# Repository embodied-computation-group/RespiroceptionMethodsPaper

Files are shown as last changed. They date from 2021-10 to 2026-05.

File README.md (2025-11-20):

# The Respiratory Resistance Sensitivity Task: An Automated Method for Quantifying Respiratory Interoception and Metacognition

This repository contains data, code and supporting documents for the manuscript:

https://www.biorxiv.org/content/10.1101/2021.10.14.464418v1

Please cite as:

>Nikolova, N., Harrison, O. K., Toohey, S., Braendholt, M., Legrand, N., Correa, C. C., Vejlo, M., Fardo, F., & Allen, M. (2021). The Respiratory Resistance Sensitivity Task: An Automated Method for Quantifying Respiratory Interoception and Metacognition. BioRxiv, 2021.10.14.464418. https://doi.org/10.1101/2021.10.14.464418

# Abstract
>The ability to sense, monitor, and control respiration - e.g., respiratory interoception (henceforth, respiroception) is a core homeostatic ability. Beyond the regulation of gas exchange, enhanced awareness of respiratory sensations is directly related to psychiatric symptoms such as panic and anxiety. Indeed, chronic breathlessness (dyspnea) is associated with a fourfold increase in the risk of developing depression and anxiety, and the regulation of the breath is a key aspect of many mindfulness-based approaches to the treatment of mental illness. Physiologically speaking, the ability to accurately monitor respiratory sensations is important for optimizing cardiorespiratory function during athletic exertion, and can be a key indicator of illness. Given the important role of respiroception in mental and physical health, it is unsurprising that there is increased interest in the quantification of respiratory psychophysiology across different perceptual and metacognitive levels of the psychological hierarchy. Compared to other more popular modalities of interoception, such as in the cardiac domain, there are relatively few methods available for measuring aspects of respiroception. Existing inspiratory loading tasks are difficult to administer and frequently require expensive medical equipment, or offer poor granularity in their quantification of respiratory-related perceptual ability. To facilitate the study of respiroception, we here present a new, fully automated and computer-controlled apparatus and psychophysiological method, which can flexibly and easily measure respiratory-related interoceptive sensitivity, bias and metacognition, in as little as 30 minutes of testing, using easy to make 3D printable parts. 

# Data
All anonymized trial and group-level data associated with this manuscript can be found here:

https://github.com/embodied-computation-group/RespiroceptionMethodsPaper/tree/main/data

# Code

This repository contains all needed code to run the RRST itself, as well as associated data preprocessing and analysis scripts.

# Figures

## Figure 1 - The Respiratory Resistance Sensitivity Task - Apparatus and Design
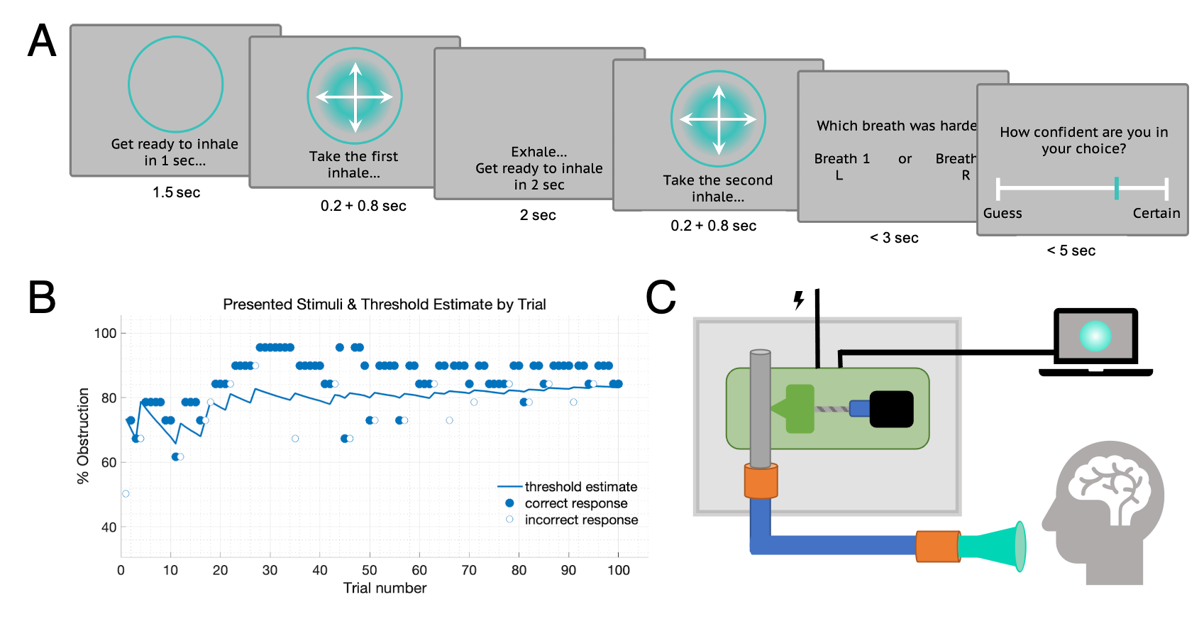
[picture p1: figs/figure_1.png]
f1


>Figure 1: The Respiratory Resistance Discrimination Task. A) Trial schematic depicting the 2-interval forced choice (2IFC) design of the task. On each trial participants view a circular cue instructing them to prepare to inhale. The circle then blinks and begins expanding, with the participant instructed to sharply inhale with the expansion of the circle. The participant then exhales, and a second similarly guided breath is conducted. This procedure of pacing the participant’s breathing via visual cues is a novel feature of the RRST, and is intended to reduce intra- and inter-subject variance in respiratory effort. Following the two breaths, the participant indicates by keyboard press whether the first or second breath was more difficult. B) Sample single subject data, illustrating the psychophysical procedure. On each trial, one of two breaths is randomly signal minus (s-), such that the compression wedge is at resting baseline (0% obstruction) with no added resistance, and the other signal plus (s+) with some level of compression determined by the staircase procedure. The procedure rapidly hones in on a threshold estimate using a Bayesian procedure (psi); in this example the participant threshold of approximately 80% obstruction is found within just 20 trials. C) Schematic illustrating the design of the automated resistive load apparatus (see Supplementary Material 1 - Detailed schematic for details). 

## Figure 2 - Respiratory Psychophysical Functions
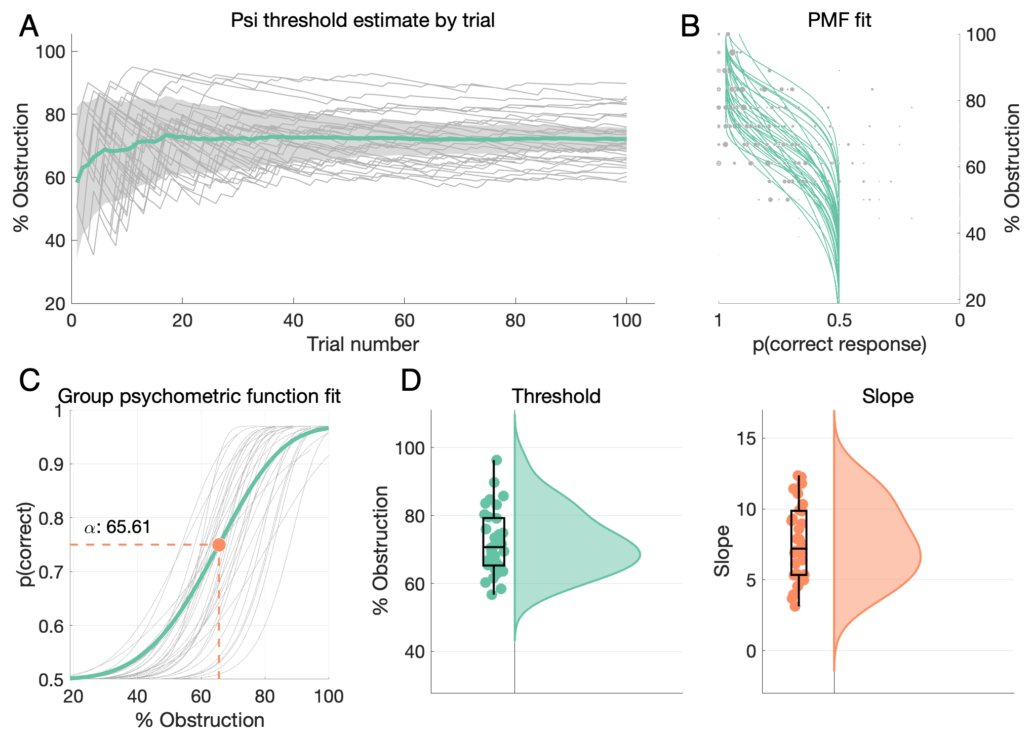
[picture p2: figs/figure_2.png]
f2


>Figure 2: Psychometric task results. A) Plot depicting trial-by-trial Psi threshold estimates for all participants. Light gray lines depict individual stimulus traces indicating the % of tube obstruction on the stimulus breath for each trial, the thick green line represents grand mean stimulus on each trial +- SEM. In general, threshold estimates stabilize around trials 20-40 for all participants. B) PMF fits for all subjects. The green lines depict individuals’ PMF fits, and grey points show stimulus levels presented, where the dot size indicates the number of times presented. C) Grand mean psychometric fit (green) overlaid on individual PMF fits (grey), demonstrating that average respiratory thresholds are around 66% airway obstruction, with substantive inter-individual variance around this value. D) Raincloud plots (Allen, Poggiali, et al., 2019) depicting individual threshold (green) and slope (orange) estimates for all subjects. 

## Figure 3 - Task Accuracy, Reaction Time, and Accuracy
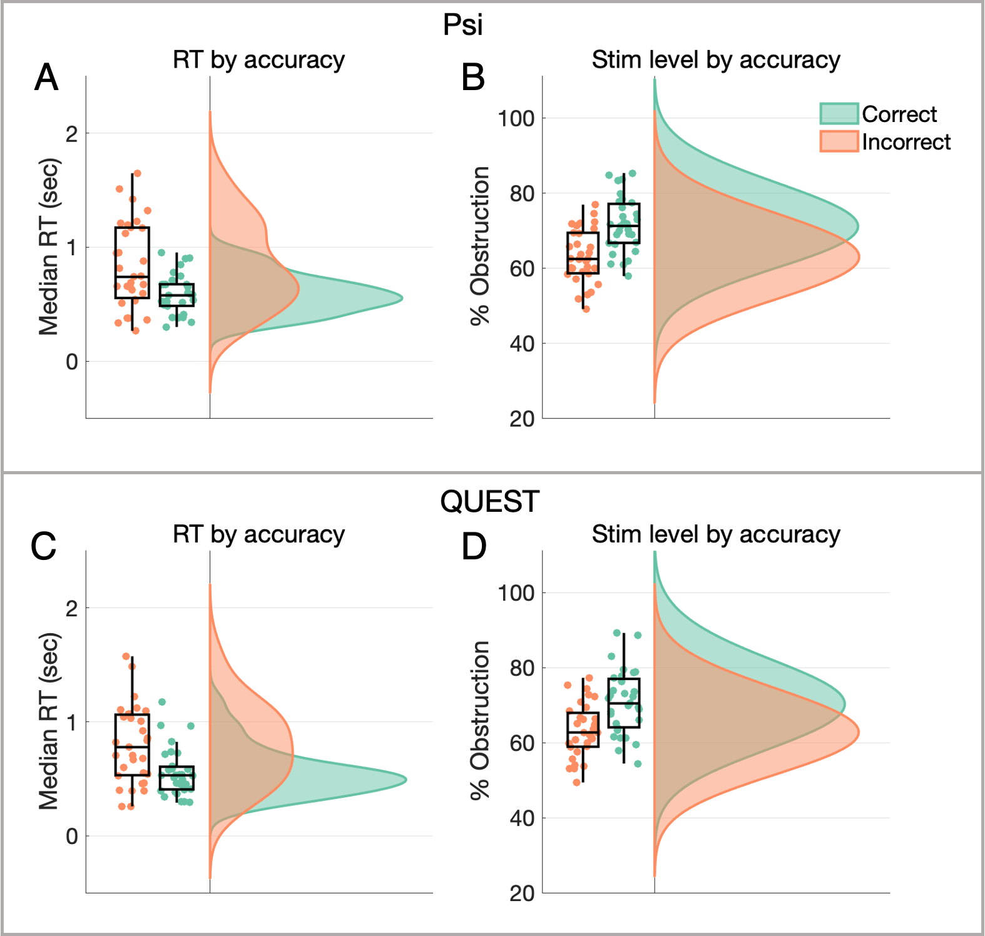
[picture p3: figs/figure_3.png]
f3


>Figure 3: Type 1 performance on Psi & QUEST methods. Raincloud plots of reaction times (RT, left panel) and stimulus level (right panel) by accuracy (correct vs. incorrect) for the Psi (upper panel) and QUEST (lower panel) staircase methods. A) & C) Median RTs presented for each subject, for correct (green) and incorrect (orange) trials showing that RTs on correct trials are lower than on incorrect trials. B) & D) Average stimulus levels presented for each subject, for correct and incorrect trials, showing that stimuli were higher (i.e., easier) on correct trials.  These results indicate good overall convergence of estimated psychometric thresholds. 

## Figure 4 - Staircase Convergence and Reliability
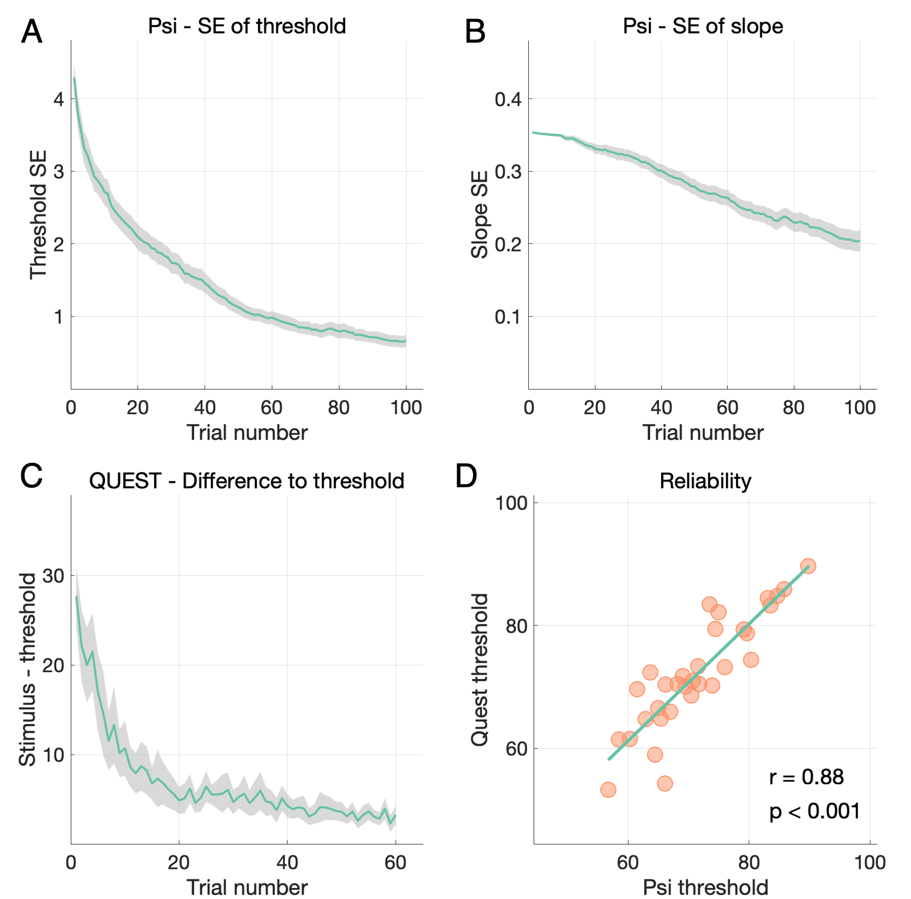
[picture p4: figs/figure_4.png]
f4


>Figure 4: Staircase convergence and Task Reliability.  A) Standard errors of the threshold estimate by trial number obtained with Psi indicate that reliable threshold estimates are derived within 20-50 trials. B) Standard errors of the slope estimate by trial number show that slope uncertainty drops linearly as a function of trials, indicating that slope estimates may benefit from higher trial numbers and/or hierarchical modelling. C) The difference to the final threshold estimates by trial number obtained with QUEST indicates that threshold estimates also converge within 20-50 trials. D) Correlation plot across the two (counter-balanced) QUEST and Psi threshold estimates indicates a high within-subject reliability of respiroceptive thresholds, regardless of estimation technique.

## Figure 5 - Respiratory Metacognition
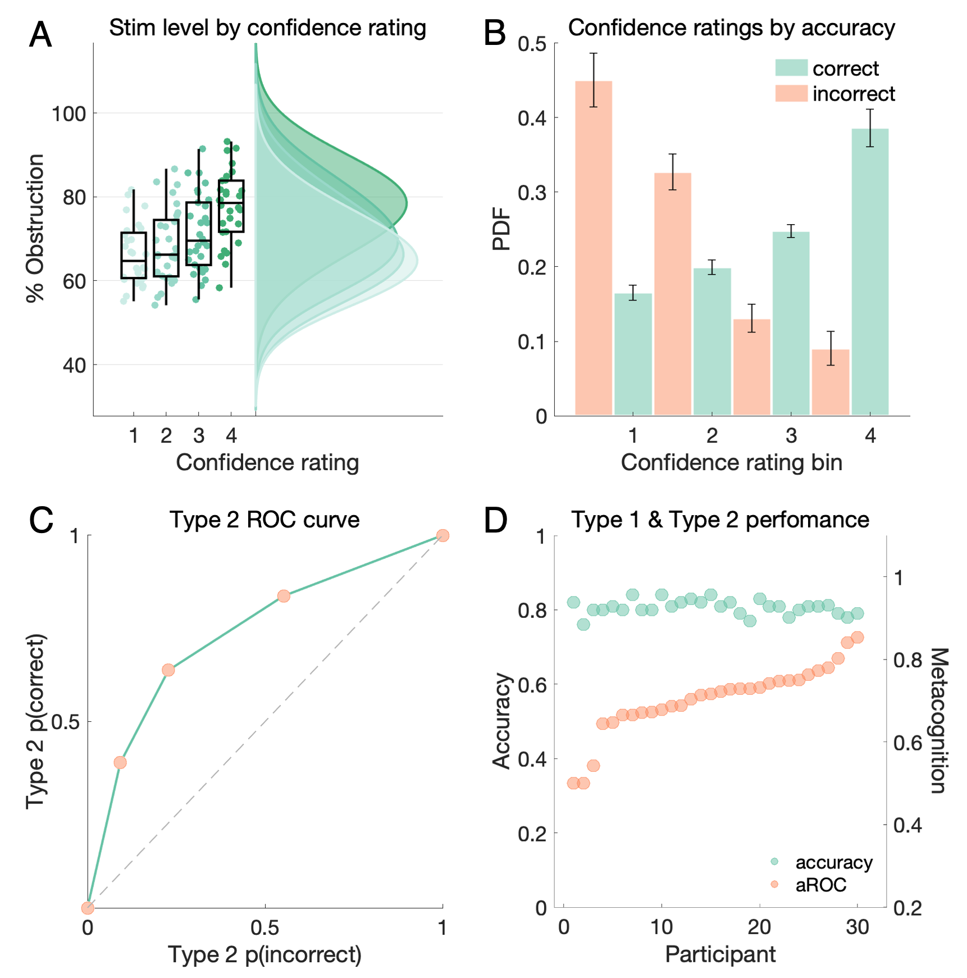
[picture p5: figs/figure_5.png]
f5


>Figure 5: Type 2 performance.  A)  Raincloud plot showing stimulus level by confidence rating, showing higher confidence ratings for stimuli with greater resistance. B)  Histogram of binned confidence ratings for correct (green) and incorrect (orange) trials. Generally, participants showed high metacognitive sensitivity, as seen in the dissociation between the correct and incorrect trial ratings. C) Type 2 ROC curve, averaged over participants, showing good respiroceptive type 2 performance. D) Type 1 (accuracy, green) and type 2 (aROC, orange) performance, sorted by each participant’s aROC. Participants show substantial variations in metacognition while type 1 accuracy is held relatively constant by the Psi staircase procedure. 

## Figure 6 - Stimulus Averiseness and other Symptoms
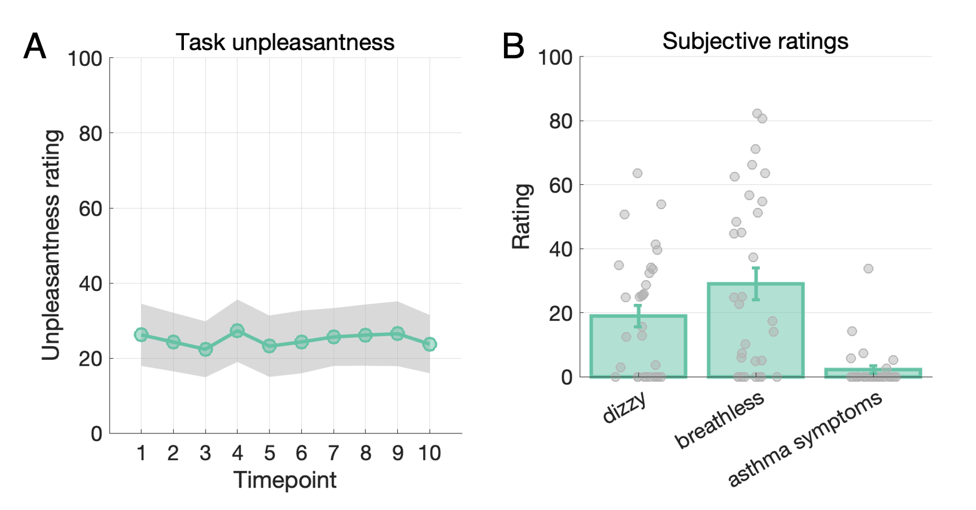
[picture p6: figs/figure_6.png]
f6


>Figure 6: Task tolerance & subjective ratings. A) Plot depicting aversiveness ratings across all 10 blocks (timepoints) of testing. Mean aversiveness ratings after each block are shown in green, and the shaded gray area represents standard error of the mean (SEM). Each block comprised 20 trials, for a total testing time of approximately 45 minutes. Participants on average reported roughly 20% stimulus aversiveness (out of 100 total), which remains stable throughout the testing period. This indicates that the stimuli were mildly unpleasant and that extended testing time did not increase task adversity within these limits. B) Plot depicting mean dizziness, breathlessness and asthma symptoms across participants. Bar height represents mean ratings, error bars denote SEM, and gray circles show individual participants’ ratings. In general, participants showed low levels of these adverse effects following 1 full hour of testing, indicating good tolerability of the task. 

# Device specifications and parts

## May 2022
We have made an update to the RRST appratus harware and software. 
An updated parts list for the device is available at: https://docs.google.com/spreadsheets/d/1Xm-xjyxZgqfn2RlGidUxHrNGNTMF7fd8MpfaUctbE9U/edit?usp=sharing
New versions of the 3d printing files, PCB design, and code for running the task are available in ./task/RRS_3-0
Instructions for setting up and running the RRST can be found here: https://docs.google.com/document/d/1KxjABdMcecnZfaXCnsQhJQzVfaNqk7DXVoDFSJKMT78/edit?usp=sharing
(Note that these were created for data collection during the COVID pandemic, and therefore include more sanitisation procedures than would usually be necessary.)

## November 2025 Update
Fixed an issue where the expanding ring stimulus was not scaling correctly on high-resolution displays. The stimulus is now generated programmatically (`showExpandingRingGenerated.m`) instead of using a pre-rendered movie file, ensuring consistent sizing and timing across different screen resolutions. This change has been applied to both the main task and the tutorial. The original movie-based method (`showExpandingRing.m`) is preserved in the codebase but commented out in the calling scripts.

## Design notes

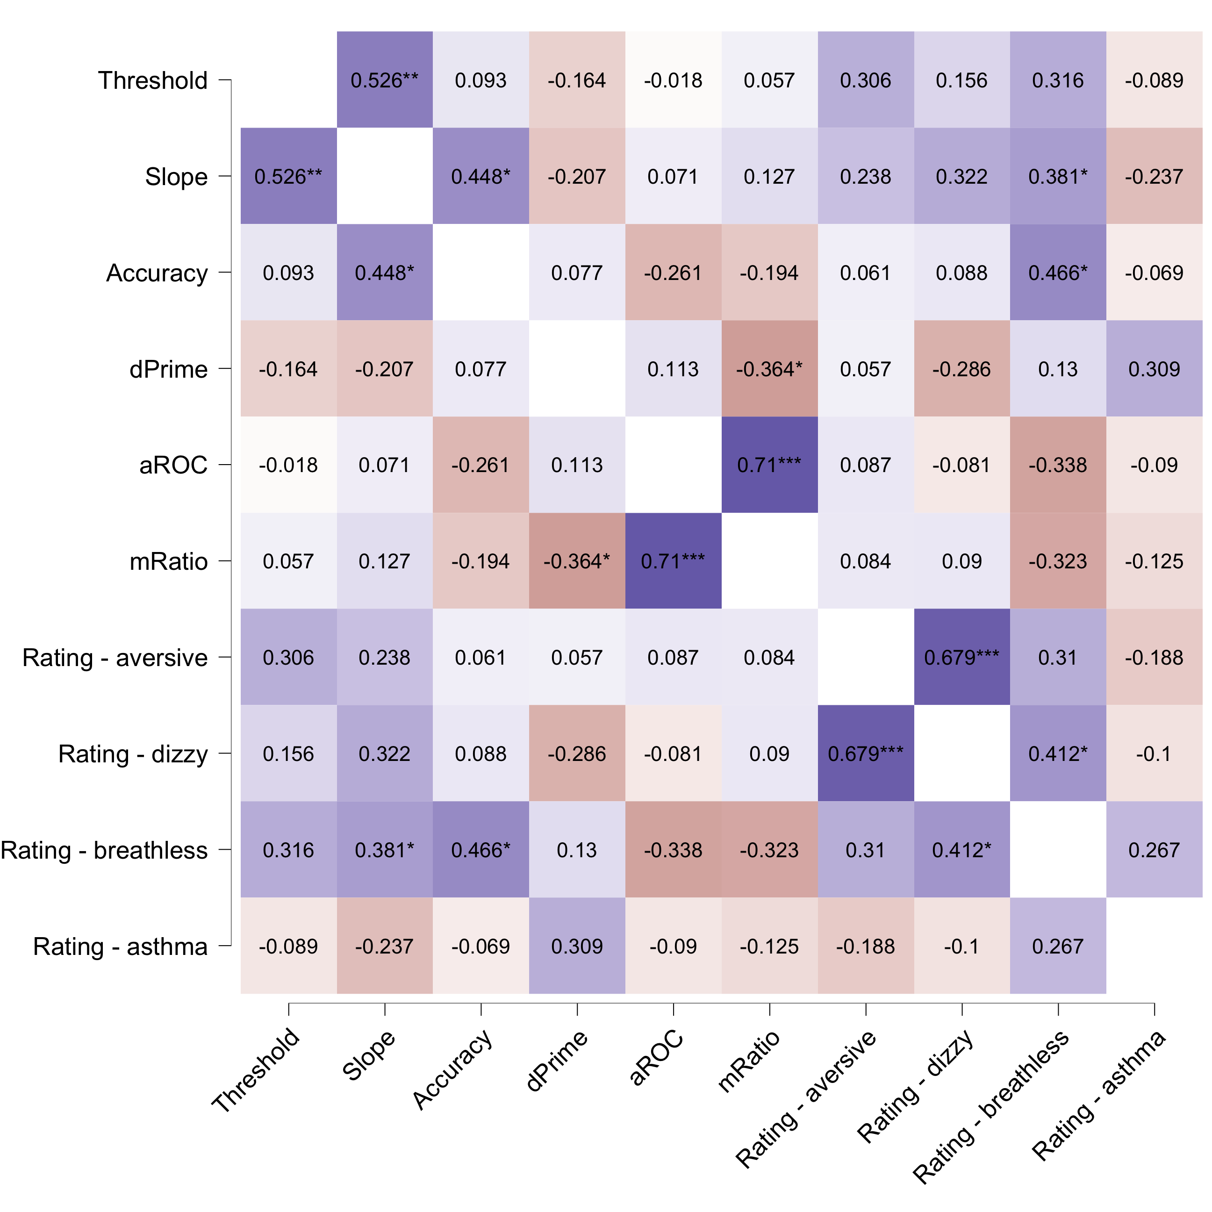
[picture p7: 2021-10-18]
figs/RRST_MP_suppfig_2.png

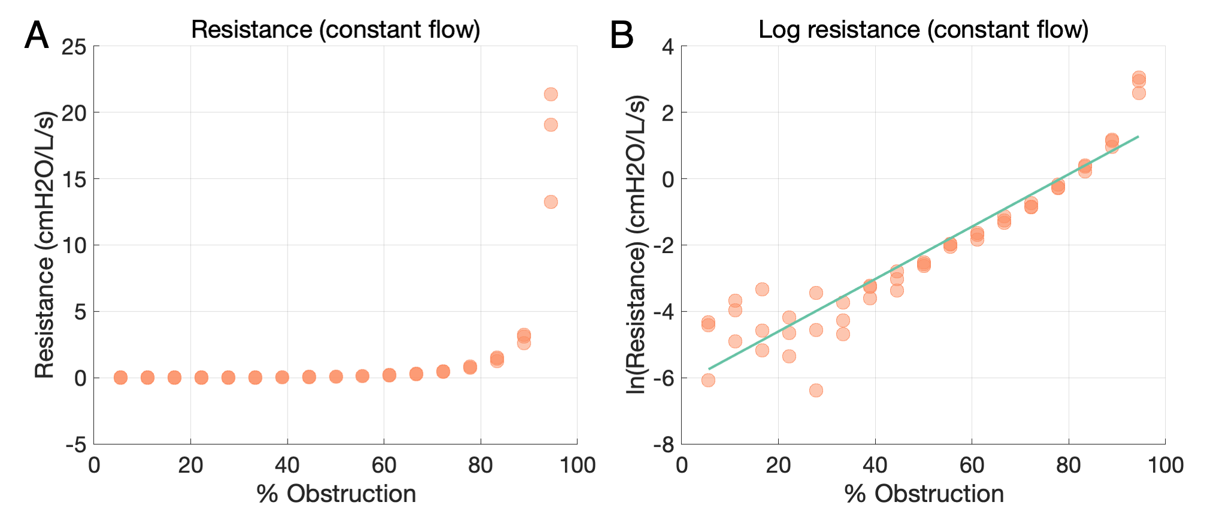
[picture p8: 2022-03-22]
figs/figure_7.png

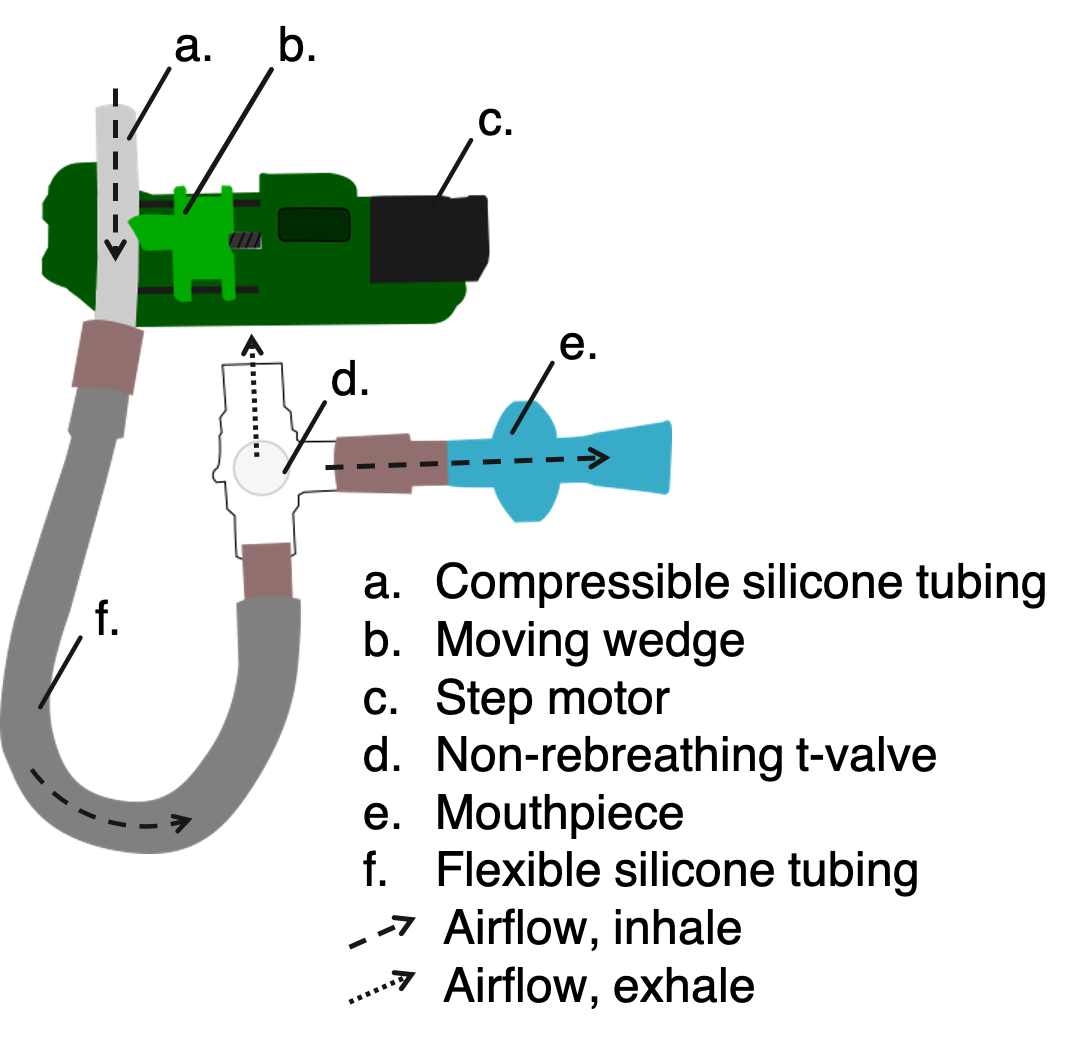
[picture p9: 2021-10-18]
figs/RRST_MP_suppfig_1.png

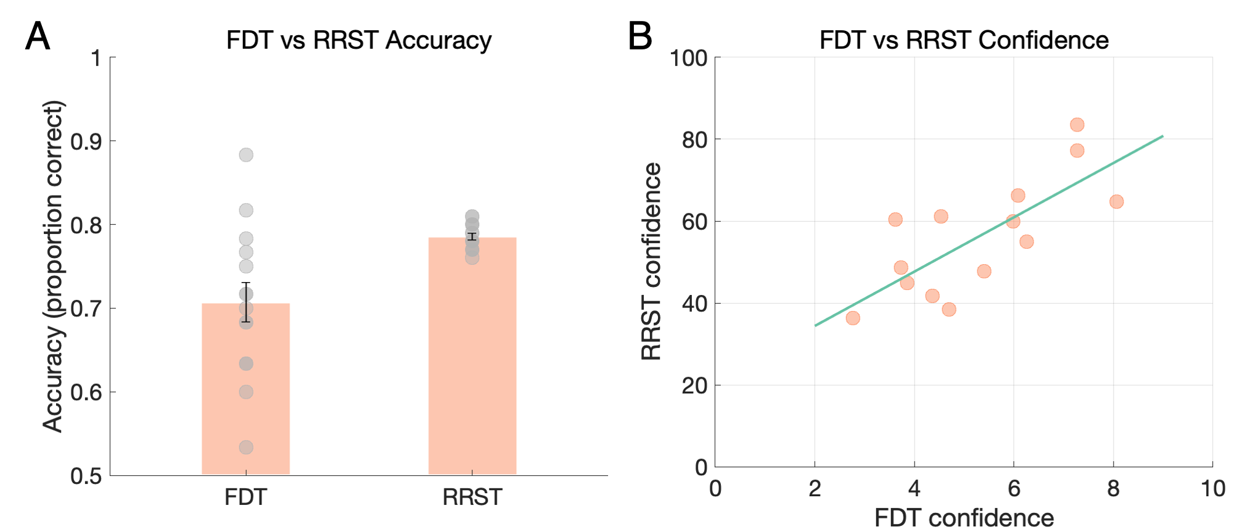
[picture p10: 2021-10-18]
figs/figure_9.png

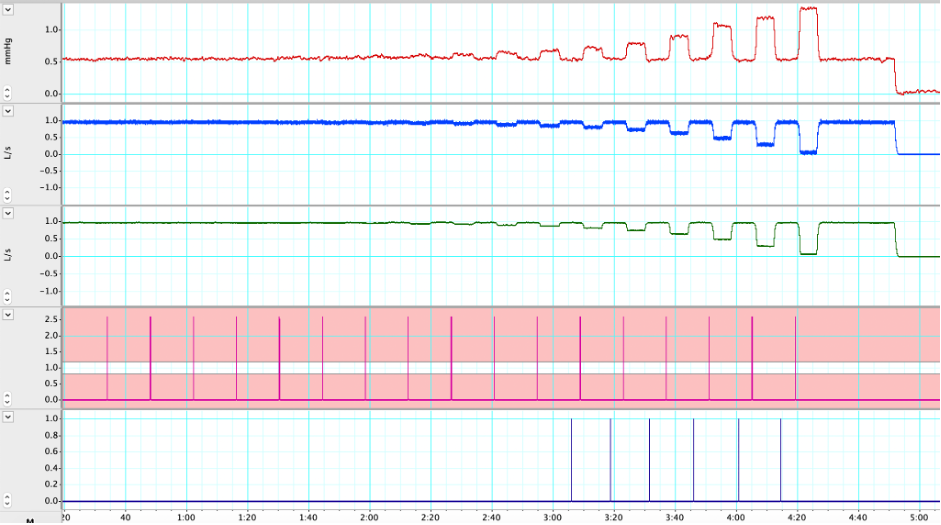
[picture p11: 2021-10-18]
figs/RRST_MP_suppfig_4.png

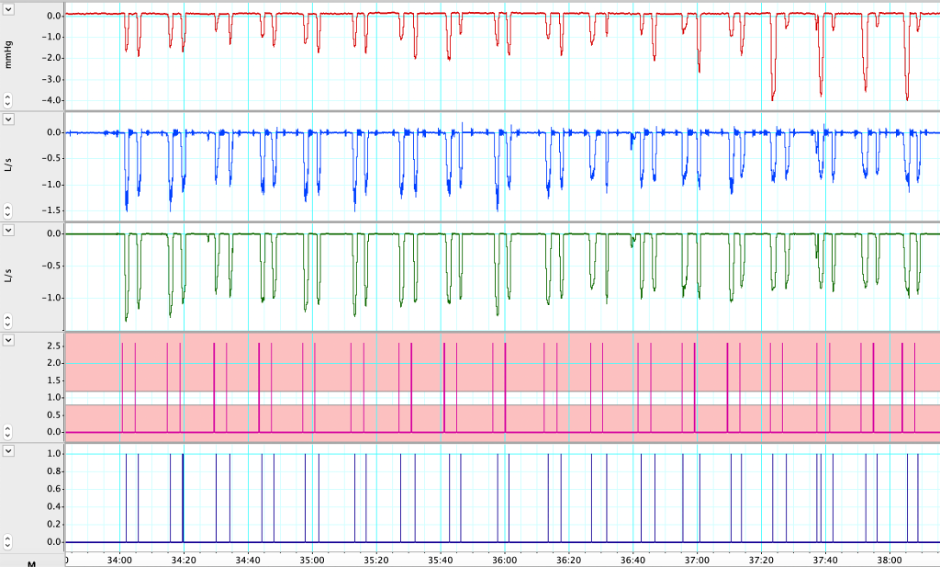
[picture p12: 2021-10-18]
figs/RRST_MP_suppfig_5.png

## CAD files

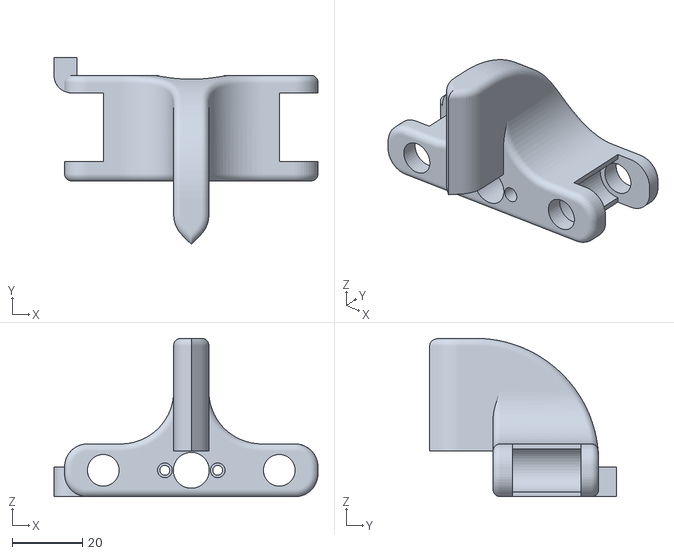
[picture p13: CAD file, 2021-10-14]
task/apparatus/version_2-2/3dPrintStlFiles/Vice_clamp.stl
75.0 x 53.0 x 45.0

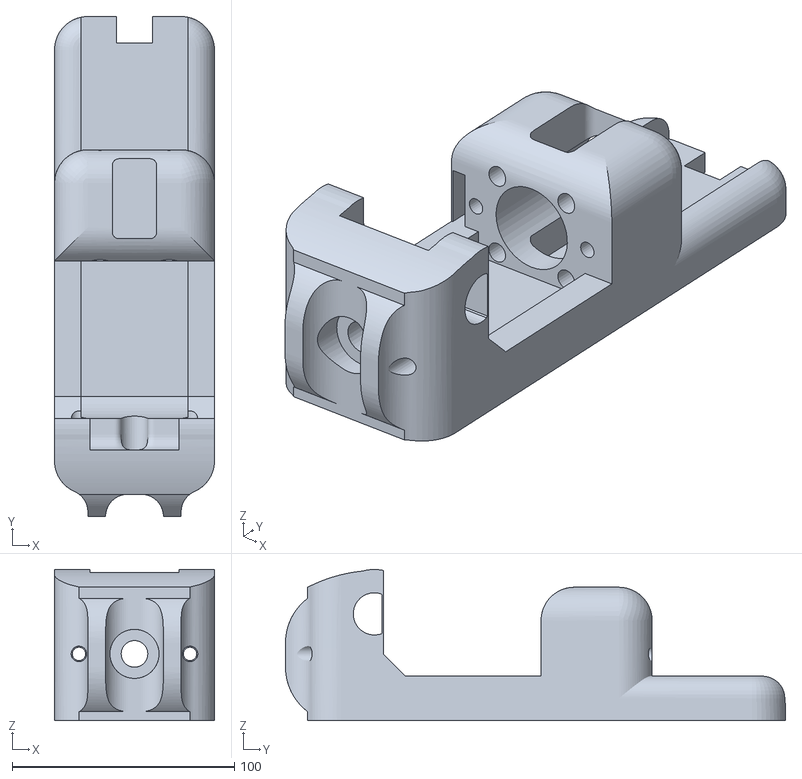
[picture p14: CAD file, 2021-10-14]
task/apparatus/version_2-2/3dPrintStlFiles/Vice_top.stl
72.0 x 225.0 x 68.0

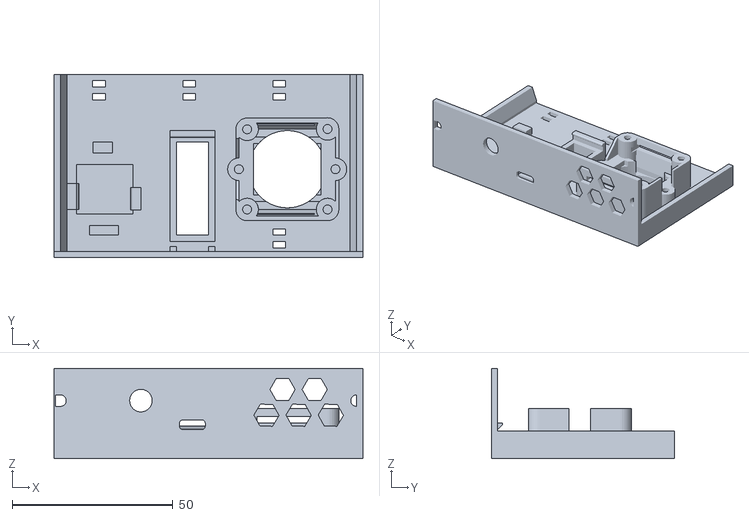
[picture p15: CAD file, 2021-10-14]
task/apparatus/version_2-2/3dPrintStlFiles/drawer.stl
96.0 x 57.0 x 28.0

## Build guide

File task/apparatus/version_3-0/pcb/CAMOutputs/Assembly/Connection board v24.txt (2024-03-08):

Partlist exported from Team Hub: Martin Jensen   Project: Martin's First Project  Board: Connection board v24 at 18/08/2023 08.40

Qty Value                    Device                           Package                     Parts        Description                                                                            CATEGORY            DESCRIPTION MANUFACTURER     MPN            OPERATING_TEMP PART_STATUS PROD_ID    ROHS_COMPLIANT  SERIES  SUB-CATEGORY THERMALLOSS       TYPE VALUE  VOLTAGE_RATING
2                            C-POL_TANTALUM-1206(3216-METRIC) CAPMP3216X180N              C5, C6       Capacitor Polarised - Generic                                                          Capacitor                                                                                                                                                                              
1                            C_CHIP-0603(1608-METRIC)         CAPC1608X85                 C4           Capacitor - Generic                                                                    Capacitor                                                                                                                                                                              
1                            C_TANTALUM-2412(6032-METRIC)     CAPM6032X280                C1           Capacitor - Generic                                                                    Capacitor                                                                                                                                                                              
1   1182-A4988               1182-A4988                       A4988                       TMC2100      A4988 Stepper Motor Driver Carrier                                                                                                                                                                                                                                            
1   JST-XH-02-PIN-LONG-PAD   JST-XH-02-PIN-LONG-PAD           JST-XH-02-PACKAGE-LONG-PAD  FAN          JST XH Connector 2 Pin                                                                                                                                                                                                                                                        
2   JST-XH-03-PIN-LONG-PAD   JST-XH-03-PIN-LONG-PAD           JST-XH-03-PACKAGE-LONG-PAD  AUX, ENDSTOP JST XH Connector 2 Pin                                                                                                                                                                                                                                                        
1   JST-XH-04-PIN-LONG-PAD   JST-XH-04-PIN-LONG-PAD           JST-XH-04-PACKAGE-LONG-PAD  STEPPER      JST XH Connector 2 Pin                                                                                                                                                                                                                                                        
1   NCP1117ST33T3G           NCP1117ST33T3GSOT-223            SOT230P700X170-4            VR1          1.0 A Low-Dropout Positive Fixed and Adjustable Voltage Regulators                     IC_Power-Management             ON Semiconductor NCP1117ST33T3G 0 to +125 °C   Active                 RoHS3 Compliant NCP1117  NCV1117     Voltage Regulator      Linear NCP1117ST33T3G
1   PINHD-1X1                PINHD-1X1                        1X01                        JP2          PIN HEADER                                                                             CONNECTOR                                                                                                                     PIN-HEADER                                               
2   PINHD-1X2                PINHD-1X2                        1X02                        JP1, JP3     PIN HEADER                                                                             CONNECTOR                                                                                                                     PIN-HEADER                                               
2   PINHD-1X3                PINHD-1X3                        1X03                        CFG1, CFG2   PIN HEADER                                                                             CONNECTOR                                                                                                                     PIN-HEADER                                               
1   POWER_JACK               POWER_JACK                       POWER_JACK_PTH              J1           Power Jack Connector                                                                                                                                                              CONN-08197                                                                                  
1   TEENSY_3.1-3.2_OUTER_ROW TEENSY_3.1-3.2_OUTER_ROW         TEENSY_3.0-3.2&LC_OUTER_ROW TEENSY       Footprint for Teensy 3.1 or 3.2 board using all pin connections on the outer perimeter                                                                                                                                                                                        
1   XM1584                   XM1584                           XM1584-TH                   XM1584

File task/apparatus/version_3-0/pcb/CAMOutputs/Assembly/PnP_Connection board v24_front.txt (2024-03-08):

C1	69.85	77.80	90.00		CAPM6032X280
C4	73.99	72.39	90.00		CAPC1608X85
C5	76.42	72.39	90.00		CAPMP3216X180N
C6	76.42	77.47	90.00		CAPMP3216X180N
VR1	83.82	79.38	0.00	NCP1117ST33T3G	SOT230P700X170-4

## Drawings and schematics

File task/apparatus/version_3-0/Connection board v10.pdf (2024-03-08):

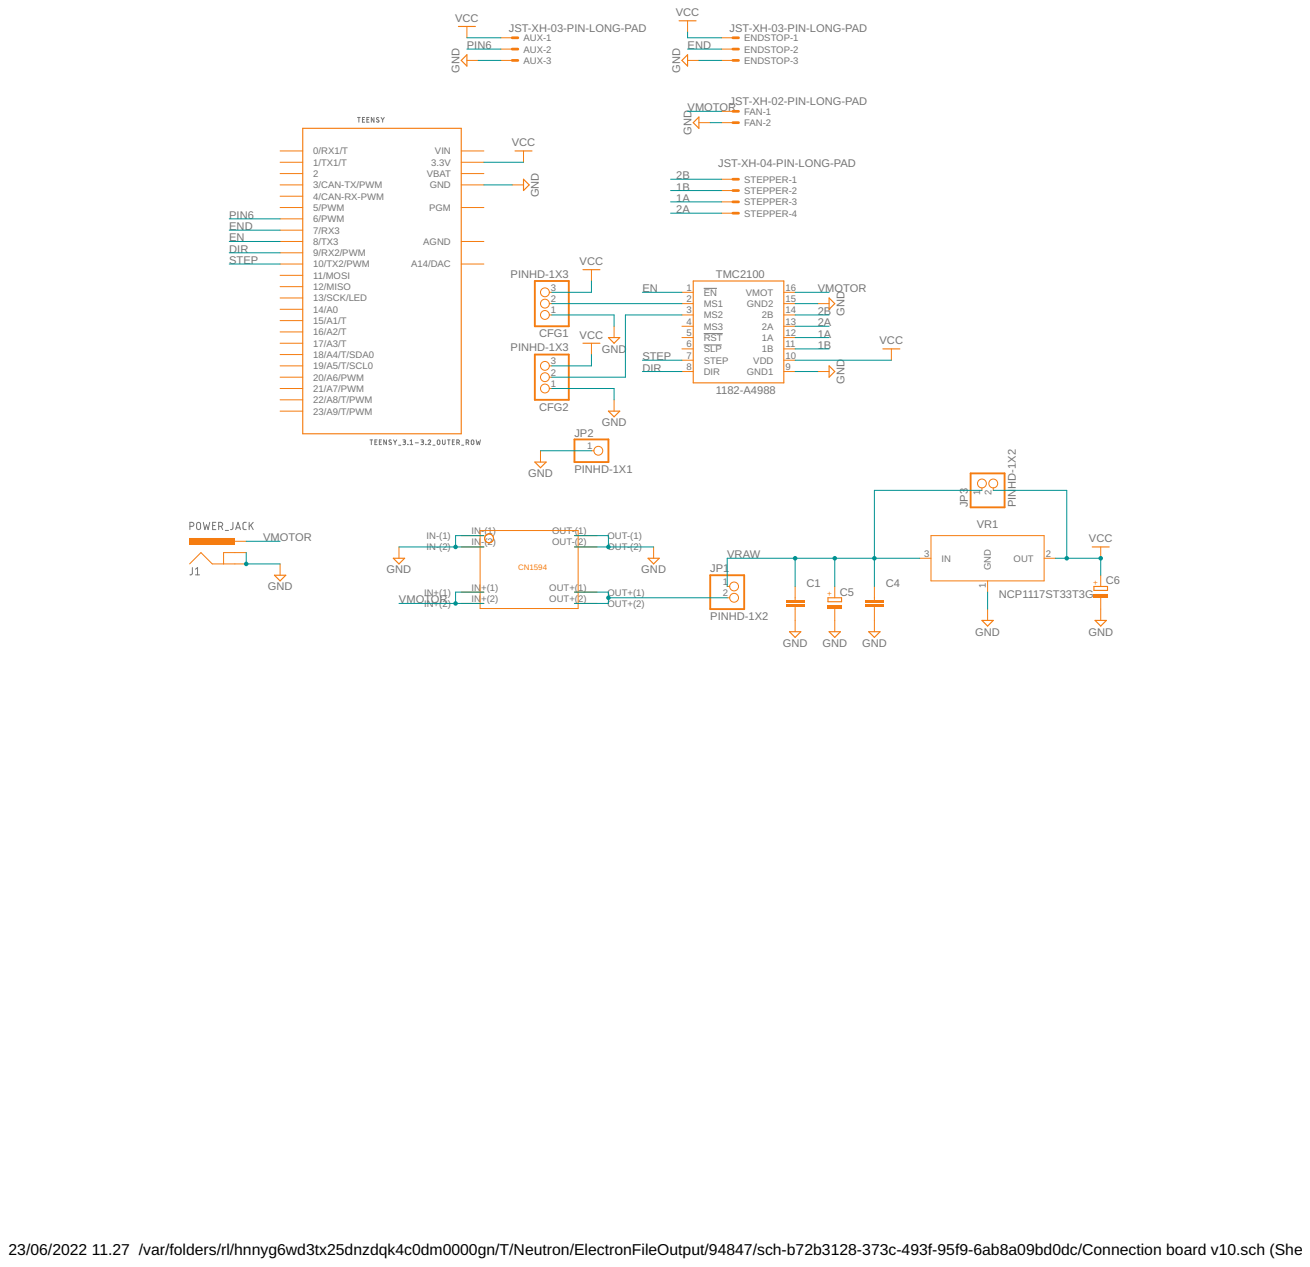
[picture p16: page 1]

JST-XH-03-PIN-LONG-PAD
AUX-1 AUX-2 AUX-3

ENDSTOP-1 ENDSTOP-2 ENDSTOP-3 FAN-2 FAN-1

JST-XH-02-PIN-LONG-PAD

JST-XH-04-PIN-LONG-PAD
STEPPER-1 STEPPER-2 STEPPER-3 STEPPER-4

23/06/2022 11.27 /var/folders/rl/hnnyg6wd3tx25dnzdqk4c0dm0000gn/T/Neutron/ElectronFileOutput/94847/sch-b72b3128-373c-493f-95f9-6ab8a09bd0dc/Connection board v10.sch (Sheet: 1/1)

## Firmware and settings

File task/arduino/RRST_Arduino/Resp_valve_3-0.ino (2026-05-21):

/**

 */

/* Includes Files (libraries) =================================================== */
#include <SerialMenuCmd.h> //Library referred to in this example
#include <TeensyStep.h>

/* Macros =============================================================================== */
#define LedOnBoard 13

#define EndstopMaxPin 6
#define EndstopMinPin 7
#define EnablePin 8
#define DirPin 9
#define StepPin 10
#define STARTPOS 20000
#define ACCELERATION 10000
#define SPEED 16000

/* Class (instanciation) =============================================================== */
/**
 * @brief Instanciation of the SerialMenuCmd library (Class)
 *        This library allows thez user(développeur) to implement a basic CLI (Common Line Interface).
 *        Operation is based on the serial monitor, for the user it consists of consulting a menu
 *        and then activating a command by sending the corresponding code.
 *        
 *        example menu (the text must include the corresponding code or othewise the key):
 *        a - todo command 1 
 *        b - todo command 2
 *        1 - todo command 3
 *        * - todo command ....
 * 
 *        The menu items are put together in a structure MenCmdItem, see further in the file
 */
SerialMenuCmd myMmuCmd;
Stepper motor(StepPin, DirPin);  
StepControl controller; 

/* Variables ============================================================================= */
uint8_t StepperStatus;
uint16_t MaxPosition = 45000;
uint8_t CalibrationStatus = 0;
uint16_t CurrentPosition = 0;
uint16_t Acceleration = ACCELERATION;
uint16_t Speed = SPEED;
uint16_t LedOnTime;
uint16_t LedOffTime;
uint32_t tEvent;
String Software;


long initial_homing=-300;


/* Variables Stepper ===================================================================== */


/* Function Prototype(s) ================================================================= */
void LedInfoUserPanic(void);

/* CLI( Command Line Interfaface) making of================================================ */
//Declaration texts of menu
tMenuCmdTxt txt1_EnableStepper[] = "e - enable stepper (normal mode)";
tMenuCmdTxt txt2_DisableStepper[] = "d - disable stepper";
tMenuCmdTxt txt3_Calibrate[] = "c - calibrate min & max";
tMenuCmdTxt txt4_Home[] = "h - home stepper";
tMenuCmdTxt txt5_SafeOperation[] = "o - Operrate with in safemode";
tMenuCmdTxt txt6_AbsoluteMove[] = "a - move to absolute position";
tMenuCmdTxt txt7_Status[] = "s - status";
tMenuCmdTxt txt8_Menu[] = "m - menu";
tMenuCmdTxt txt9_Speed[] = "f - speed";
tMenuCmdTxt txt10_Acceleration[] = "g - acceleration";

tMenuCmdTxt txt3_DisplayMenu[] = "? - Displaying menu";

//Declaration text of prompt
tMenuCmdTxt txt_Prompt[] = "Valve";

//Prototype of function which are callback by the library
void cmd1_EnableStepper(void);
void cmd2_DisableStepper(void);
void cmd3_Calibrate(void);
void cmd4_Home(void);
void cmd5_SafeOperation(void);
void cmd6_AbsoluteMove(void);
void cmd7_Status(void);
void cmd8_Menu(void);
void cmd9_Speed(void);
void cmd10_Acceleration(void);

//Structure initialisation
//Data type
//array sMenuTxt, code (character) , function (Reminder the code character must be printable character)
stMenuCmd list[] = {
    {txt1_EnableStepper, 'e', cmd1_EnableStepper},
    {txt2_DisableStepper, 'd', cmd2_DisableStepper},
    {txt3_Calibrate, 'c', cmd3_Calibrate},
    {txt4_Home, 'h', cmd4_Home},
    {txt5_SafeOperation, 'o', cmd5_SafeOperation},
    {txt6_AbsoluteMove, 'a', cmd6_AbsoluteMove},  
    {txt7_Status, 's', cmd7_Status},  
    {txt8_Menu, 'm', cmd8_Menu},
    {txt9_Speed, 'f', cmd9_Speed},
    {txt10_Acceleration, 'g', cmd10_Acceleration}
};

//KmenuCount contains the number of command
#define NbCmds sizeof(list) / sizeof(stMenuCmd)


/* Functions Implementation =================================================== */

/**
 * @brief Standard function Arduino for initialisation
 * 
 */
void setup()
{
  //Activate and initialize the serial bus with the baudrate passed in parameter
  Serial.begin(115200);

  //Setup stepper speed and acceleration
    motor
  .setAcceleration(Acceleration)
  .setMaxSpeed(Speed);
  
  // Configure Endstops
  pinMode(EndstopMinPin,INPUT_PULLUP);
  pinMode(EndstopMaxPin,INPUT_PULLUP);
  // Configure Enable pin for driver TMC2100
  pinMode(EnablePin,OUTPUT);

  //Configure the pin to wich  the Led on board the card is connected
  pinMode(LedOnBoard, OUTPUT);
  //switch off the led
  digitalWrite(LedOnBoard, LOW);

  //Reset variables
  StepperStatus = 0;
  LedOnTime = 1000;
  LedOffTime = 1000;
  tEvent = 0;
  Software = "2022r0";

  //Initialize the library with structure defined by the user
  if (myMmuCmd.begin(list, NbCmds, txt_Prompt) == false)
  {
    //If the initialization fails, the system informs the user via the
    //led: panic mode, led flashes in Morse code the letters "SOS"
    while (true)
    {
      LedInfoUserPanic();
    }
  }

  //Display the menu
  myMmuCmd.ShowMenu();
  myMmuCmd.giveCmdPrompt();
 
}

/**
 * @brief Function standard Arduino to repeat the tasks
 * 
 */
void loop()
{
  uint8_t CmdCode;

  /**
   * @brief management of the interaction between the system and the user.
   * The "UserRequest" menbre function analyzes the characters transmitted by the user. 
   * If an command code is identified, its number is returned (return 0 if no command). This 
   * function is not blocking, it stores the intermediate data between 2 calls. 
   */
  CmdCode = myMmuCmd.UserRequest();

  //possible pre-treatment here

  /**
   * @brief Execute Command
   * if a command code is returned, the system executes the corresponding command. 
   * To do this, it uses the "OpsCallback" member function. this function receives 
   * the command code parameter
   * 
   * @note In this way, it is possible to carry out a preprocessing and postprocessing
   */
  if (CmdCode != 0)
  {
    myMmuCmd.ExeCommand(CmdCode);
  }
  

  /**
   * @brief Switch on, off or blink the led
   * 
   */
  switch(StepperStatus)
  {
    case 0: //Switch off 
      //before switching off the led check that it is on
      if(digitalRead(LedOnBoard) == true){
        digitalWrite(LedOnBoard, false);
      }
      break;

    case 1: //switch on led
      //before switching on the led check that it is off
      if(digitalRead(LedOnBoard) == false){
        digitalWrite(LedOnBoard, true);
      }
      break;

    case 2:
      //if reached event duration
      //tEvent is a timestamp in millisecond
      if(millis() >= tEvent)
      {
        //if led is off
        if(digitalRead(LedOnBoard) == true)
        {
          //Programm next event with led duration off
          tEvent = millis() + LedOffTime;
          digitalWrite(LedOnBoard, false);
        }
        else
        {
          //Programm next event with led duration on
          tEvent = millis() + LedOnTime;
          digitalWrite(LedOnBoard, true);
        }
      }
      break;

    default:
      break;
  }
}

/**
 * @brief Flash led on-board in morse code
 * 
 */
void LedInfoUserPanic(void)
{
  /**
   * @brief Timing Morse
   * Letter S -> 3 dot (short mark)
   * Letter O -> 3 dash (long mark)
   * 1 dot => 1 unit time
   * 1 dash => 3 units time
   * 1 intra-character space => 1 units time
   * 1 inter-character space => 3 units time
   * 1 word space => 7 untis time  
   * 
   */
  

}


/**
 * @brief 
 * 
 */
void cmd1_EnableStepper(void)
{
  StepperStatus = 1;  
  Serial.println("");
  Serial.println(F("Stepper enabled in normal mode"));
  Serial.println("");
  digitalWrite(EnablePin,LOW);
  detachInterrupt(digitalPinToInterrupt(EndstopMinPin));
  detachInterrupt(digitalPinToInterrupt(EndstopMaxPin));
  myMmuCmd.giveCmdPrompt();
}


/**
 * @brief 
 * 
 */
void cmd2_DisableStepper(void)
{
  StepperStatus = 0;
  Serial.println("");
  Serial.println(F("Stepper disabled"));
  digitalWrite(EnablePin,HIGH);
  myMmuCmd.giveCmdPrompt();
}

/**
 * @brief 
 * 
 */
void cmd3_Calibrate(void)
{
  Acceleration=ACCELERATION;
  Speed=SPEED;
  motor.setAcceleration(Acceleration);
  motor.setMaxSpeed(Speed);
  StepperStatus = 2;
  cmd4_Home();
  motor.setTargetRel(38000);
  controller.move(motor);
  delay(2000);
  while (digitalRead(EndstopMaxPin)==0) {  // Make the Stepper move CCW until the switch is activated   
  //digitalWrite(LED_BUILTIN,HIGH);
  motor.setTargetRel(200);  // Set the position to move to
  controller.move(motor);   // Start moving the stepper
  delay(4);
  }
  MaxPosition= motor.getPosition();
  motor.setTargetAbs(STARTPOS);
  controller.move(motor);    // Do the move
  //myMmuCmd.giveCmdPrompt();
}

/**
 * @brief 
 * 
 */
void cmd4_Home(void)
{


Serial.println("Fast Homing begins:");
  int endstopStatus = digitalRead(EndstopMinPin);
  Serial.println(endstopStatus);
 
 
  while (digitalRead(EndstopMinPin)==0) {  // Make the Stepper move CCW until the switch is activated   
  digitalWrite(LED_BUILTIN,HIGH);
  motor.setTargetRel(initial_homing);  // Set the position to move to
  controller.move(motor);   // Start moving the stepper
  delay(4);
  }

  digitalWrite(LED_BUILTIN,LOW);
  Serial.println("Fast Homing ended");
  endstopStatus = digitalRead(EndstopMinPin);
  Serial.println(endstopStatus);
  
  Serial.println("Stepping forward");
  Serial.println( motor.getPosition());
  motor.setTargetRel(2000);
  controller.move(motor);
  delay(600);
  endstopStatus = digitalRead(EndstopMinPin);
  Serial.println("Re-homing ");
  Serial.println(endstopStatus);
  Serial.println( motor.getPosition());
 

 while (digitalRead(EndstopMinPin)==0) {  // Make the Stepper move CCW until the switch is activated   
  motor.setTargetRel(-5);  // Set the position to move to
  controller.move(motor);   // Start moving the stepper
  Serial.println( motor.getPosition());
  delay(3);
  }
  endstopStatus = digitalRead(EndstopMinPin);
  Serial.println("Homed ");
  Serial.println(endstopStatus);
  motor.setPosition(0);
  
 //                        1         2         3         4         5
 //               12345678901234567890123456789012345678901234567890123
 /*String aValue = "! Enter config of LED switch on time ( value in ms) ";

  if(myMmuCmd.getStrValue(aValue) == true)
  {
    Serial.println(F(""));
    Serial.print(F("Duration of LED switch on = "));
    LedOnTime = atoi(aValue.c_str());
    Serial.println(LedOnTime);
  }
  Serial.println(F(""));
  myMmuCmd.giveCmdPrompt();*/
}

void cmd5_SafeOperation(void)
{
    attachInterrupt(digitalPinToInterrupt(EndstopMinPin), EndstopMinPin_isr, RISING);
    attachInterrupt(digitalPinToInterrupt(EndstopMaxPin), EndstopMaxPin_isr, RISING );
    Serial.println(F(""));
    Serial.print(F("Not implemented"));
    Serial.println(F(""));

}

void cmd6_AbsoluteMove(void)
{
  
 String aValue = "! Enter absolute move: ";

  if(myMmuCmd.getStrOfChar(aValue) == true)
  {
    Serial.println(F(""));
    Serial.print(F("Moving to = "));
    CurrentPosition = atoi(aValue.c_str());
    Serial.println(CurrentPosition);
    //motor.setTargetAbs(CurrentPosition);
    
    elapsedMillis MoveTime;
// Set the target position:
  if(CurrentPosition <= MaxPosition)
  {
    motor.setTargetAbs(CurrentPosition);
    controller.move(motor);    // Do the move
  
  }
  else if (CurrentPosition > MaxPosition)
  {
    CurrentPosition = MaxPosition;
    Serial.print("Out of range! Setting position to Max: ");
    Serial.println(CurrentPosition);
    motor.setTargetAbs(CurrentPosition);
    controller.move(motor);    // Do the move
  }
    Serial.print("Move time (ms) ");
    Serial.println(MoveTime);
  }
  Serial.println(F(""));
  myMmuCmd.giveCmdPrompt();

}

/**
 * @brief 
 * 
 */
void cmd7_Status(void)
{
  Serial.println(F(""));
  Serial.println(F("General status :"));
  Serial.print(F("- Stepper status = "));
  switch(StepperStatus)
  {
    case 0:
      Serial.println(F("disabled"));
      break;

    case 1:
      Serial.println(F("enabled"));
      break;

    case 2:
      Serial.println(F("moving"));
      break;

    default:
      Serial.println(F("undetermined"));
      break;
  }

  Serial.print(F("- Stepper position (step) = "));
  Serial.println(CurrentPosition);

  Serial.print(F("- Stepper Maximum (steps) = "));
  Serial.println(MaxPosition);

  Serial.print(F("- Minimum endstop state = "));
  Serial.println(digitalRead(EndstopMinPin));

  Serial.print(F("- Maximum endstop state = "));
  Serial.println(digitalRead(EndstopMaxPin));
  
  Serial.print(F("- Stepper speed (steps/s) = "));
  Serial.println(Speed);

  Serial.print(F("- Stepper acceleration (steps/s^2) = "));
  Serial.println(Acceleration);


  Serial.print(F("- Software = "));
  Serial.println(Software);
  myMmuCmd.giveCmdPrompt();
}

/**
 * @brief 
 * 
 */
void cmd8_Menu(void)
{
  myMmuCmd.ShowMenu();
  myMmuCmd.giveCmdPrompt();
}

void cmd9_Speed(void)
{
 String aValue = "! Enter stepper maximum speed (steps/s) ";

  if(myMmuCmd.getStrValue(aValue) == true)
  {
    Serial.println(F(""));
    Serial.print(F("Current Speed = "));
    Serial.println(Speed);
    Serial.print(F("Set speed to (steps/s) = "));
    Speed = atoi(aValue.c_str());
    Serial.println(Speed);
    motor.setMaxSpeed(Speed);
  }
  Serial.println(F(""));
  myMmuCmd.giveCmdPrompt();  

}

void cmd10_Acceleration(void)
{
 String aValue = "! Enter stepper acceleration (steps/s^2) ";

  if(myMmuCmd.getStrValue(aValue) == true)
  {
    Serial.println(F(""));
    Serial.print(F("Acceleration set to (steps/s^2) = "));
    Acceleration = atoi(aValue.c_str());
    Serial.println(Acceleration);
    motor.setAcceleration(Acceleration);

  }
  Serial.println(F(""));
  myMmuCmd.giveCmdPrompt();  

}


void EndstopMinPin_isr(void)
{
  controller.emergencyStop();
 // motor.setPosition(0);
 // motor.setTargetAbs(CurrentPosition);
  //controller.move(motor);    // Do the move
  Serial.println(F(""));
  Serial.print(F("Endstop min hit! "));
}


void EndstopMaxPin_isr(void)
{
  controller.emergencyStop();
//  motor.setPosition(MaxPosition);
//  motor.setTargetAbs(CurrentPosition);
//  controller.move(motor);    // Do the move
  Serial.println(F(""));
  Serial.print(F("Endstop max hit!"));
}

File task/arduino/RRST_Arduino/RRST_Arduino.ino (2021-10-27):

/*==========================================================================

 ===========================================================================*/

#include "TeensyStep.h"

#define endstopPin 7
#define enablePin 8
#define dirPin 9
#define stepPin 10

#define MAXPOSITION 37000

long initial_homing=-200;

//Serial interface setup
const byte numChars = 90;
char receivedChars[numChars];
boolean newData = false;

long stepperPosition = 0;

Stepper motor(stepPin, dirPin);      
  
StepControl controller;    // Use default settings 

void setup()
{
  Serial.begin(9600);
  
  motor
  .setAcceleration(10000) // 20 000
  .setMaxSpeed(16000);

  // Setting up Endstop pin
  pinMode(endstopPin,INPUT_PULLUP);

  // Setting up enable pin and enable the driver
  pinMode(enablePin,OUTPUT);
  digitalWrite(enablePin,LOW);

  // Setup LED pin for debugging  
  pinMode(LED_BUILTIN, OUTPUT);

  // Home the stepper
  homeStepper();
  
}

void loop() 
{

  recvWithEndMarker();
  showNewNumber(); 



motor.setTargetAbs(stepperPosition);

// Set the target position:
  if(stepperPosition <= MAXPOSITION && stepperPosition >= 0)
  {
    motor.setTargetAbs(stepperPosition);
    controller.move(motor);    // Do the move
  
  }
  else if (stepperPosition > MAXPOSITION)
  {
    stepperPosition = MAXPOSITION;
    Serial.print("Out of range! Setting position to MAXPOSITION: ");
    Serial.println(stepperPosition);
    motor.setTargetAbs(stepperPosition);
    controller.move(motor);    // Do the move
  }
  else if (stepperPosition < 0)
  {
    homeStepper();
  }


}

// Serial receive function
void recvWithEndMarker() {
    static byte ndx = 0;
    char endMarker = '\n';
    char rc;
    
    if (Serial.available() > 0) {
        rc = Serial.read();
        Serial.print((char)rc);

        if (rc != endMarker) {
            receivedChars[ndx] = rc;
            ndx++;
            if (ndx >= numChars) {
                ndx = numChars - 1;
            }
        }
        else {
            receivedChars[ndx] = '\0'; // terminate the string
            ndx = 0;
            newData = true;
        }
    }
}

void showNewNumber() {
    if (newData == true) {
        Serial.print("Current position: ");
        Serial.println(stepperPosition);
        stepperPosition = 0;             // new for this version
        stepperPosition = atol(receivedChars);   // new for this version
        Serial.print("New position: ");
        Serial.println(receivedChars);
        newData = false;
    }
}


// Homing routine
void homeStepper(){

  Serial.println("Fast Homing begins:");
  int endstopStatus = digitalRead(endstopPin);
  Serial.println(endstopStatus);

  while (digitalRead(endstopPin)) {  // Make the Stepper move CCW until the switch is activated   
  motor.setTargetRel(initial_homing);  // Set the position to move to
  controller.move(motor);   // Start moving the stepper
  delay(4);
  }
  
  Serial.println("Fast Homing ended");
  endstopStatus = digitalRead(endstopPin);
  Serial.println(endstopStatus);
  
  Serial.println("Stepping forward");
  Serial.println( motor.getPosition());
  motor.setTargetRel(2000);
  controller.move(motor);
  delay(600);
  endstopStatus = digitalRead(endstopPin);
  Serial.println("Re-homing ");
  Serial.println(endstopStatus);
  Serial.println( motor.getPosition());
 

 while (digitalRead(endstopPin)) {  // Make the Stepper move CCW until the switch is activated   
  motor.setTargetRel(-5);  // Set the position to move to
  controller.move(motor);   // Start moving the stepper
  Serial.println( motor.getPosition());
  delay(3);
  }
  endstopStatus = digitalRead(endstopPin);
  Serial.println("Homed ");
  Serial.println(endstopStatus);
  stepperPosition = 0; 
  motor.setPosition(0);
}

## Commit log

2021-10-14 data initial commit
    [FDTvsRRST.csv, NZfdtRrstAccuracy.csv, NZfdtRrstConfidence.csv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]
2021-10-14 add 3D printing (stl) files
    [Vice_clamp.stl, Vice_top.stl, drawer.stl]
2021-10-14 add constant flow data
    [NZ_constant_flow_rrst.csv]
2021-10-27 add arduino software to be uploaded on RRST device
2024-03-08 device: update 3d print and pcb files
    [Vice_clamp.stl, Vice_top.stl, drawer.stl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]
2026-05-21 Add files via upload
    New version of the Arduino code, which includes two stop pins.
2026-06-04 Add files via upload
    Modified Arduino code for support of newer Teensy 4.0 and TMC2209 driver. Generously developed and shared by David Mckiernan at Bangor University.
